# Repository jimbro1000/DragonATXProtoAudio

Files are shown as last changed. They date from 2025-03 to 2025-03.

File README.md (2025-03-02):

# Dragon 32 ATX Prototype Audio

This repository contains the KiCad project files
to produce the Audio component board for my
ATX Prototype backplane.

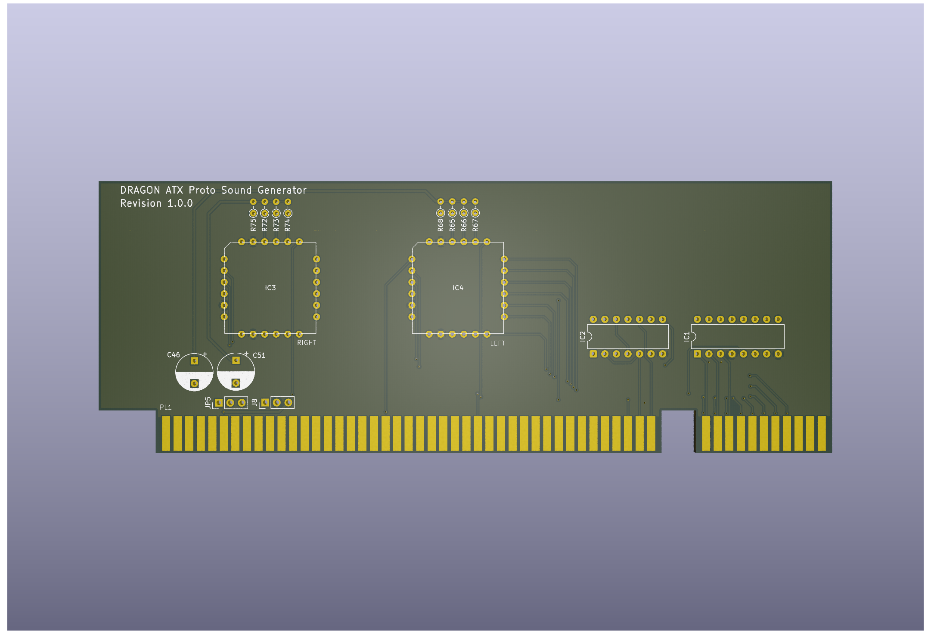
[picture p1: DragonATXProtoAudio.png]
Render of PCB top


This design requires the ATX backplane board in order 
to operate
See https://github.com/jimbro1000/DragonATXProto

## Notes

Revision 1 includes provision for two emulated AY 
sound generators. Each is dedicated to one stereo
channel, both are mixed to create a single central
channel for output over the regular composite
monitor output.

The board can be implemented with just the left
sound generator.

This design has been completed using KiCad 9. Earlier
versions of KiCad are not compatible.

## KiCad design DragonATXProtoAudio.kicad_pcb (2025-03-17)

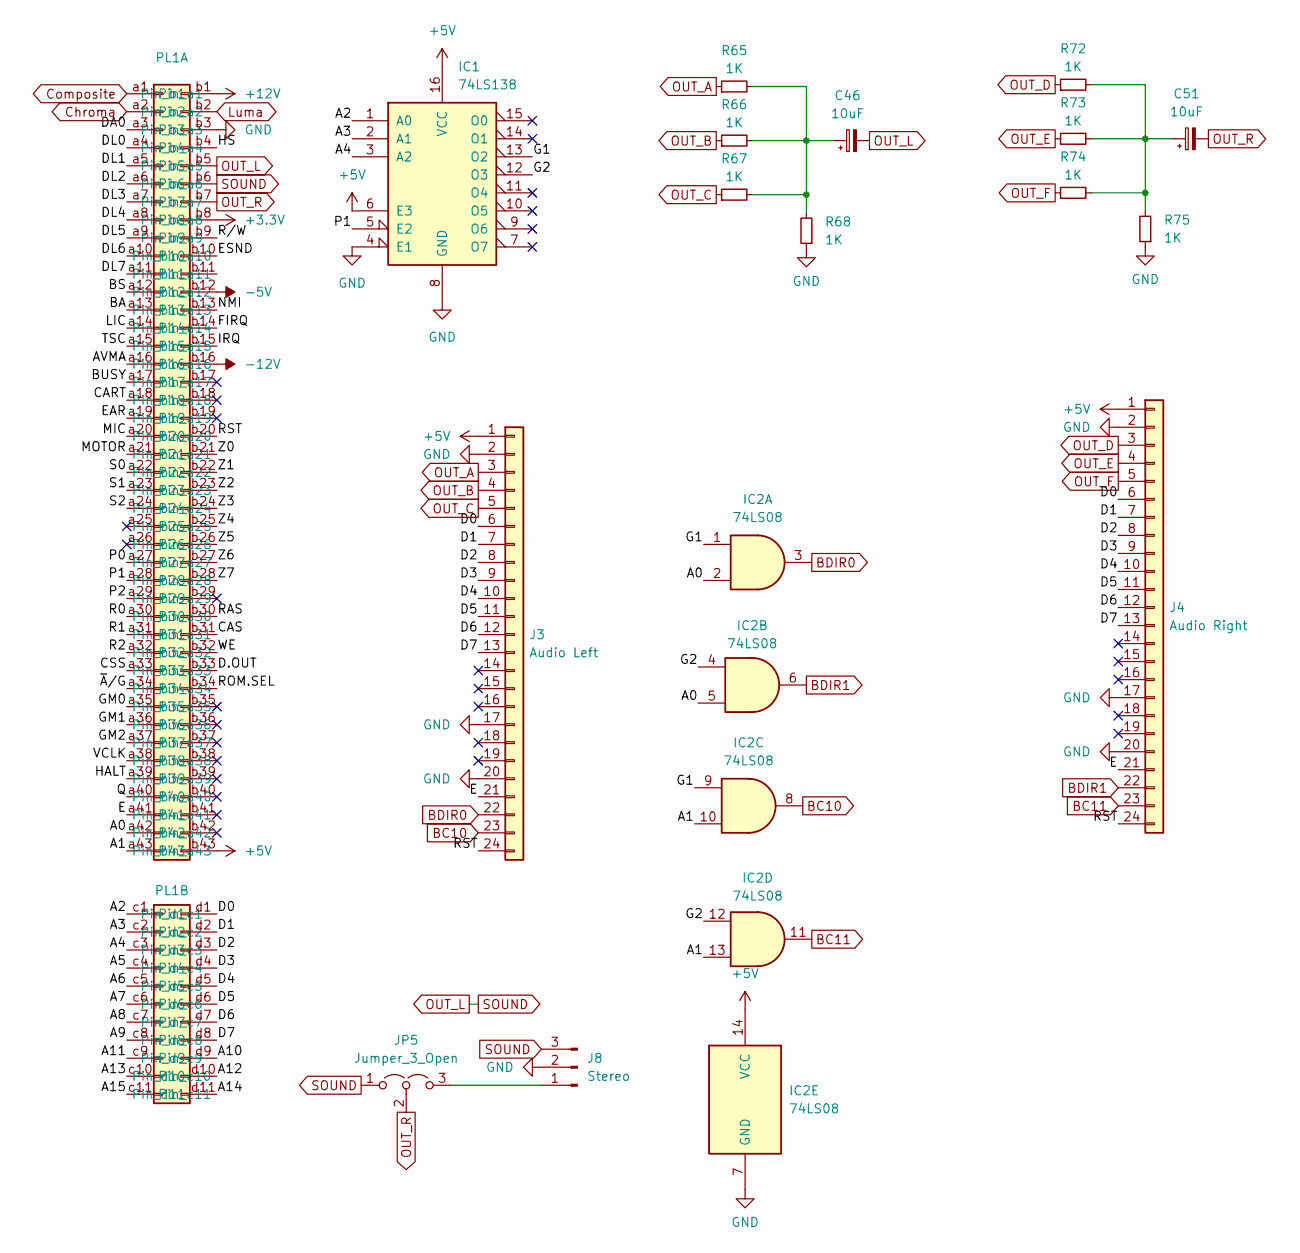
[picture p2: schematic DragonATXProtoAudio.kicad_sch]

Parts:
C46, C51: 10uF; CP_Radial_D8.0mm_P5.00mm
IC1: 74LS138; DIP-16_W7.62mm
IC2: 74LS08; DIP-14_W7.62mm
J3: Audio Left; AY-QTHT
J4: Audio Right; AY-QTHT
J8: Stereo; PinHeader_1x03_P2.54mm_Vertical
JP5: Jumper_3_Open; PinHeader_1x03_P2.54mm_Vertical
PL1: Card_Edge
R65, R66, R67, R68, R72, R73, R74, R75: 1K; R_Axial_DIN0204_L3.6mm_D1.6mm_P2.54mm_Vertical

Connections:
+3.3V: PL1.b8
+5V: IC1.6 (E3), IC1.16 (VCC), IC2.14 (VCC), J3.1, J4.1, PL1.b43
+12V: PL1.b1
-5V: PL1.b12
-12V: PL1.b16
/A0: IC2.2, IC2.5, PL1.a42
/A1: IC2.10, IC2.13, PL1.a43
/A2: IC1.1 (A0), PL1.c1
/A3: IC1.2 (A1), PL1.c2
/A4: IC1.3 (A2), PL1.c3
/A5: PL1.c4
/A6: PL1.c5
/A7: PL1.c6
/A8: PL1.c7
/A9: PL1.c8
/A10: PL1.d9
/A11: PL1.c9
/A12: PL1.d10
/A13: PL1.c10
/A14: PL1.d11
/A15: PL1.c11
/AVMA: PL1.a16
/BA: PL1.a13
/BS: PL1.a12
/BUSY: PL1.a17
/CART: PL1.a18
/CAS: PL1.b31
/CSS: PL1.a33
/D0: J3.6, J4.6, PL1.d1
/D1: J3.7, J4.7, PL1.d2
/D2: J3.8, J4.8, PL1.d3
/D3: J3.9, J4.9, PL1.d4
/D4: J3.10, J4.10, PL1.d5
/D5: J3.11, J4.11, PL1.d6
/D6: J3.12, J4.12, PL1.d7
/D7: J3.13, J4.13, PL1.d8
/D.OUT: PL1.b33
/DA0: PL1.a3
/DL0: PL1.a4
/DL1: PL1.a5
/DL2: PL1.a6
/DL3: PL1.a7
/DL4: PL1.a8
/DL5: PL1.a9
/DL6: PL1.a10
/DL7: PL1.a11
/E: J3.21, J4.21, PL1.a41
/EAR: PL1.a19
/ESND: PL1.b10
/FIRQ: PL1.b14
/G1: IC1.13 (O2), IC2.1, IC2.9
/G2: IC1.12 (O3), IC2.4, IC2.12
/GM0: PL1.a35
/GM1: PL1.a36
/GM2: PL1.a37
/HALT: PL1.a39
/HS: PL1.b4
/IRQ: PL1.b15
/LIC: PL1.a14
/MIC: PL1.a20
/MOTOR: PL1.a21
/NMI: PL1.b13
/P0: PL1.a27
/P1: IC1.5 (E2), PL1.a28
/P2: PL1.a29
/Q: PL1.a40
/R0: PL1.a30
/R1: PL1.a31
/R2: PL1.a32
/RAS: PL1.b30
/ROM.SEL: PL1.b34
/RST: J3.24, J4.24, PL1.b20
/R/W: PL1.b9
/S0: PL1.a22
/S1: PL1.a23
/S2: PL1.a24
/TSC: PL1.a15
/VCLK: PL1.a38
/WE: PL1.b32
/Z0: PL1.b21
/Z1: PL1.b22
/Z2: PL1.b23
/Z3: PL1.b24
/Z4: PL1.b25
/Z5: PL1.b26
/Z6: PL1.b27
/Z7: PL1.b28
/~A/G: PL1.a34
BC10: IC2.8, J3.23
BC11: IC2.11, J4.23
BDIR0: IC2.3, J3.22
BDIR1: IC2.6, J4.22
Chroma: PL1.a2
Composite: PL1.a1
GND: IC1.4 (E1), IC1.8 (GND), IC2.7 (GND), J3.2, J3.17, J3.20, J4.2, J4.17, J4.20, J8.2, PL1.b3, R68.1, R75.1
Luma: PL1.b2
unnamed: C46.1, R65.2, R66.2, R67.2, R68.2
unnamed: C51.1, R72.2, R73.2, R74.2, R75.2
unnamed: J8.1, JP5.3 (B)
OUT_A: J3.3, R65.1
OUT_B: J3.4, R66.1
OUT_C: J3.5, R67.1
OUT_D: J4.3, R72.1
OUT_E: J4.4, R73.1
OUT_F: J4.5, R74.1
OUT_L: C46.2, J8.3, JP5.1 (A), PL1.b5, PL1.b6
OUT_R: C51.2, JP5.2 (C), PL1.b7

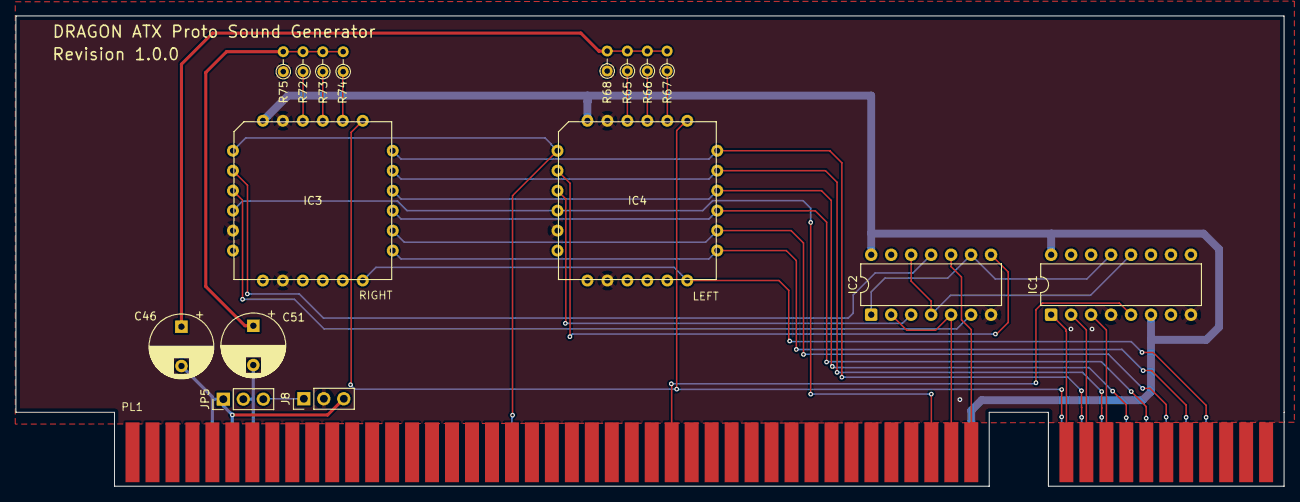
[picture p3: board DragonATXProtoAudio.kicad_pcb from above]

Board: 2 copper layers, 161.3 x 59.8 mm, 17 parts (0 on the bottom side), 35 nets.

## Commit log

2025-03-17 upgrade card edge spec
    [DragonATXProtoAudio.kicad_pcb]
2025-03-17 fix routing for new card edge spec
    [DragonATXProtoAudio.kicad_pcb]
